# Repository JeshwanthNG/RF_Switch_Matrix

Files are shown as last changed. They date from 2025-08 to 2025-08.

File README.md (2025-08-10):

# RF_Switch_Matrix
Project Implementing RF Switch Matrix, Includes hardware, software and PC application 

## Getting Started

### Prerequisites

- **Windows** for GUI development
- **Visual Studio 2022** with .NET desktop development workload
- **STM32CubeIDE** or **STM32CubeMX** with preferred IDE
- **STM32F439ZI** development board

### Clone the repository

```bash
git clone https://github.com/JeshwanthNG/RF_Switch_Matrix.git
cd RF_Switch_Matrix

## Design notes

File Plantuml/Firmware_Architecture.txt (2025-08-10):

@startuml

skinparam shadowing false
skinparam defaultTextAlignment center
skinparam componentStyle rectangle
skinparam packageStyle rectangle
skinparam ArrowColor Black
skinparam Rectangle {
  BorderColor Black
}

' =================== LAYERS ===================
package "Application Layer" #F0F8FF {
  component "StartThread\n(init, netif, LwIP bring-up)" as APP_START
  component "DisplayTask\n(UI state machine)" as APP_DISP
  component "KeypadTask\n(4x4 scan + debounce)" as APP_KEYPAD
  component "UART Console Task\n(prvUARTCommandConsoleTask)" as APP_CLI
  component "RF Switch Control\n(rfswitch.c)" as APP_RFSW
  component "TCP Echo Server\n(tcpecho.c)" as APP_TCP
  component "UDP Echo Server\n(udpecho.c)" as APP_UDP
}

package "Middleware" #F5FFFA {
  component "FreeRTOS\n(CMSIS-RTOS API)" as OS
  component "FreeRTOS+CLI\n(FreeRTOS_CLI.c)" as CLI
  component "LwIP (Netconn)\n(app_ethernet.c, ethernetif.c)" as LWIP
  component "EEPROM Emulation\n(eeprom.c)" as EEP
}

package "HAL / Drivers" #FFFFF0 {
  component "STM32 HAL\n(GPIO, ETH, USART, TIM)" as HAL
  component "GPIO Driver\n(gpio.c)" as DRV_GPIO
  component "USART Driver\n(usart.c)" as DRV_USART
}

package "Hardware" #FFF0F5 {
  component "STM32F439ZI\n(Cortex-M4F)" as MCU
  component "ETH PHY + RJ45" as ETHPHY
  component "LCD (Text)\n(lcd.c)" as LCD
  component "Keypad 4x4\n(Keypad.c)" as KEYPAD
  component "RF Switch Matrix (8× 1P4T)\n(GPIO-controlled)" as RFMAT
  component "Flash (EEPROM Emu)" as FLASH
}

' =================== QUEUES / IPC ===================
queue "keypadQueue\n(xQueue<KEYPAD_CODES>)" as Q_KEYPAD

' =================== RELATIONSHIPS: APP -> MW -> DRV -> HW ===================

' App tasks use RTOS
APP_START -down-> OS
APP_DISP  -down-> OS
APP_KEYPAD -down-> OS
APP_CLI -down-> OS
APP_TCP -down-> OS
APP_UDP -down-> OS
APP_RFSW -down-> OS

' CLI uses FreeRTOS+CLI
APP_CLI -down-> CLI

' Networking
APP_START -down-> LWIP : netif init\nDHCP_thread
APP_TCP -down-> LWIP : Netconn API
APP_UDP -down-> LWIP : Netconn API

' EEPROM emulation
APP_DISP -down-> EEP : load/save config
APP_CLI  -down-> EEP : read/write params

' RF switch control module
APP_DISP -down-> APP_RFSW : set routes
APP_CLI  -down-> APP_RFSW : cli: switch-set\nstatus

' Display <-> Keypad via queue
APP_KEYPAD -right-> Q_KEYPAD : xQueueSend
Q_KEYPAD -right-> APP_DISP : xQueueReceive

' Middleware to HAL/Drivers
LWIP -down-> HAL
CLI  -down-> HAL
EEP  -down-> HAL

' Drivers to HAL core
DRV_GPIO -down-> HAL
DRV_USART -down-> HAL

' HAL to MCU / Peripherals
HAL -down-> MCU
HAL -down-> ETHPHY
HAL -down-> LCD
HAL -down-> KEYPAD

' Drivers to Hardware via HAL
APP_RFSW -down-> DRV_GPIO : GPIO writes
DRV_GPIO -down-> RFMAT : select lines

APP_CLI -down-> DRV_USART : UART RX/TX
DRV_USART -down-> MCU

' UI plumbing
APP_DISP -down-> LCD : print strings\nmenus
APP_KEYPAD -down-> KEYPAD : scan rows/cols

' LwIP plumbing
LWIP -down-> ETHPHY : MAC <-> PHY

' EEPROM emulation uses on-chip Flash
EEP -down-> FLASH : pages/sectors

' =================== NOTES ===================
note right of APP_START
- Initializes HAL, clocks
- Starts LwIP (netif, DHCP_thread)
- Spawns UI/CLI tasks
end note

note right of APP_DISP
- Startup screen, menu
- Switch status page
- Settings pages (ETH, baud)
end note

note right of APP_RFSW
- Maps INx <-> OUTy
- Uses GPIO pin tables
- Readback status APIs
end note

note bottom of APP_CLI
Commands in CLI-commands.c:
- switch set/get
- show status
- net info (IP/DHCP)
end note

@enduml

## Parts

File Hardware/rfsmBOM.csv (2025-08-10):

Id | Designator | Package | Quantity | Designation | Supplier and ref
1 | J14,J13 | PinSocket_1x02_P2.54mm_Vertical | 2 | Conn_01x02_Male
2 | U1 | ST_Morpho_Connector_144_STLink | 1 | NUCLEO144-F439ZI
3 | C15,C16,C14,C13,C12,C11,C10,C9,C1,C4,C5,C7 | C_0805_2012Metric_Pad1.18x1.45mm_HandSolder | 12 | 0.1uf
4 | C17,C2,C8 | CP_EIA-2012-12_Kemet-R_Pad1.30x1.05mm_HandSolder | 3 | 22uf
5 | REF**,REF**,REF**,REF** | MountingHole_2.2mm_M2 | 4 | MountingHole_2.2mm_M2
6 | U9,U3,U4,U5,U6,U7,U8,U10 | DIP-14_W7.62mm_Socket | 8 | 74125
7 | C3,C6 | CP_EIA-2012-12_Kemet-R_Pad1.30x1.05mm_HandSolder | 2 | 10uf
8 | J1 | BarrelJack_Horizontal | 1 | Barrel_Jack_Switch_Pin3Ring
9 | J2 | PinSocket_1x16_P2.54mm_Vertical | 1 | LCD20x4
10 | J3 | PinSocket_1x08_P2.54mm_Vertical | 1 | Conn_01x08_Male
11 | J4 | JST_EH_B4B-EH-A_1x04_P2.50mm_Vertical | 1 | Conn_01x04_Male
12 | J5,J6,J7,J8,J9,J10,J11,J12 | JST_EH_B6B-EH-A_1x06_P2.50mm_Vertical | 8 | Conn_01x06_Male
13 | Q1 | SOT-23 | 1 | BC547
14 | R1 | R_0805_2012Metric_Pad1.20x1.40mm_HandSolder | 1 | 1k
15 | R2,R3,R4,R5,R6 | R_0805_2012Metric_Pad1.20x1.40mm_HandSolder | 5 | 4.7k
16 | RV1 | Potentiometer_Bourns_3296W_Vertical | 1 | R_POT
17 | U2,U11 | TO-220-3_Vertical | 2 | L7805

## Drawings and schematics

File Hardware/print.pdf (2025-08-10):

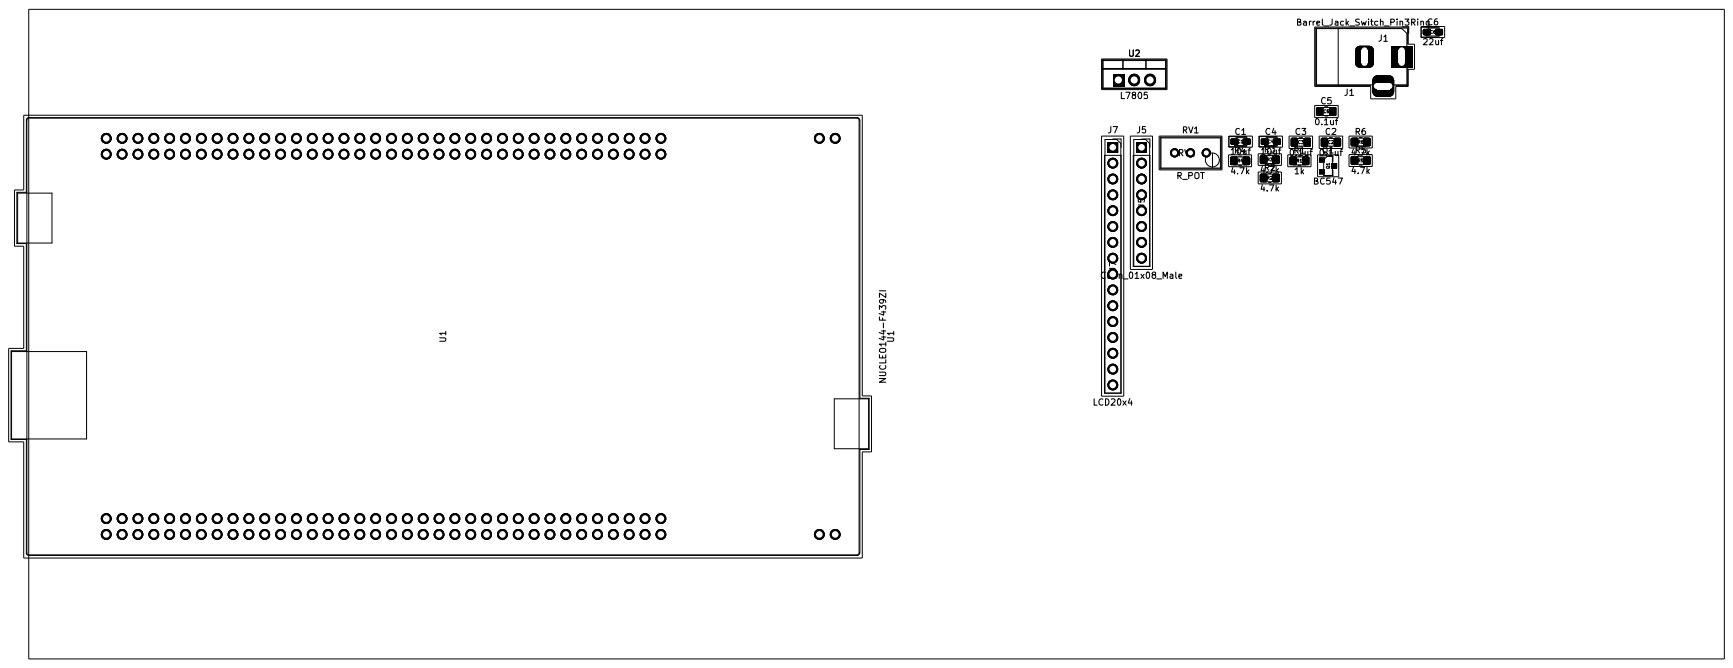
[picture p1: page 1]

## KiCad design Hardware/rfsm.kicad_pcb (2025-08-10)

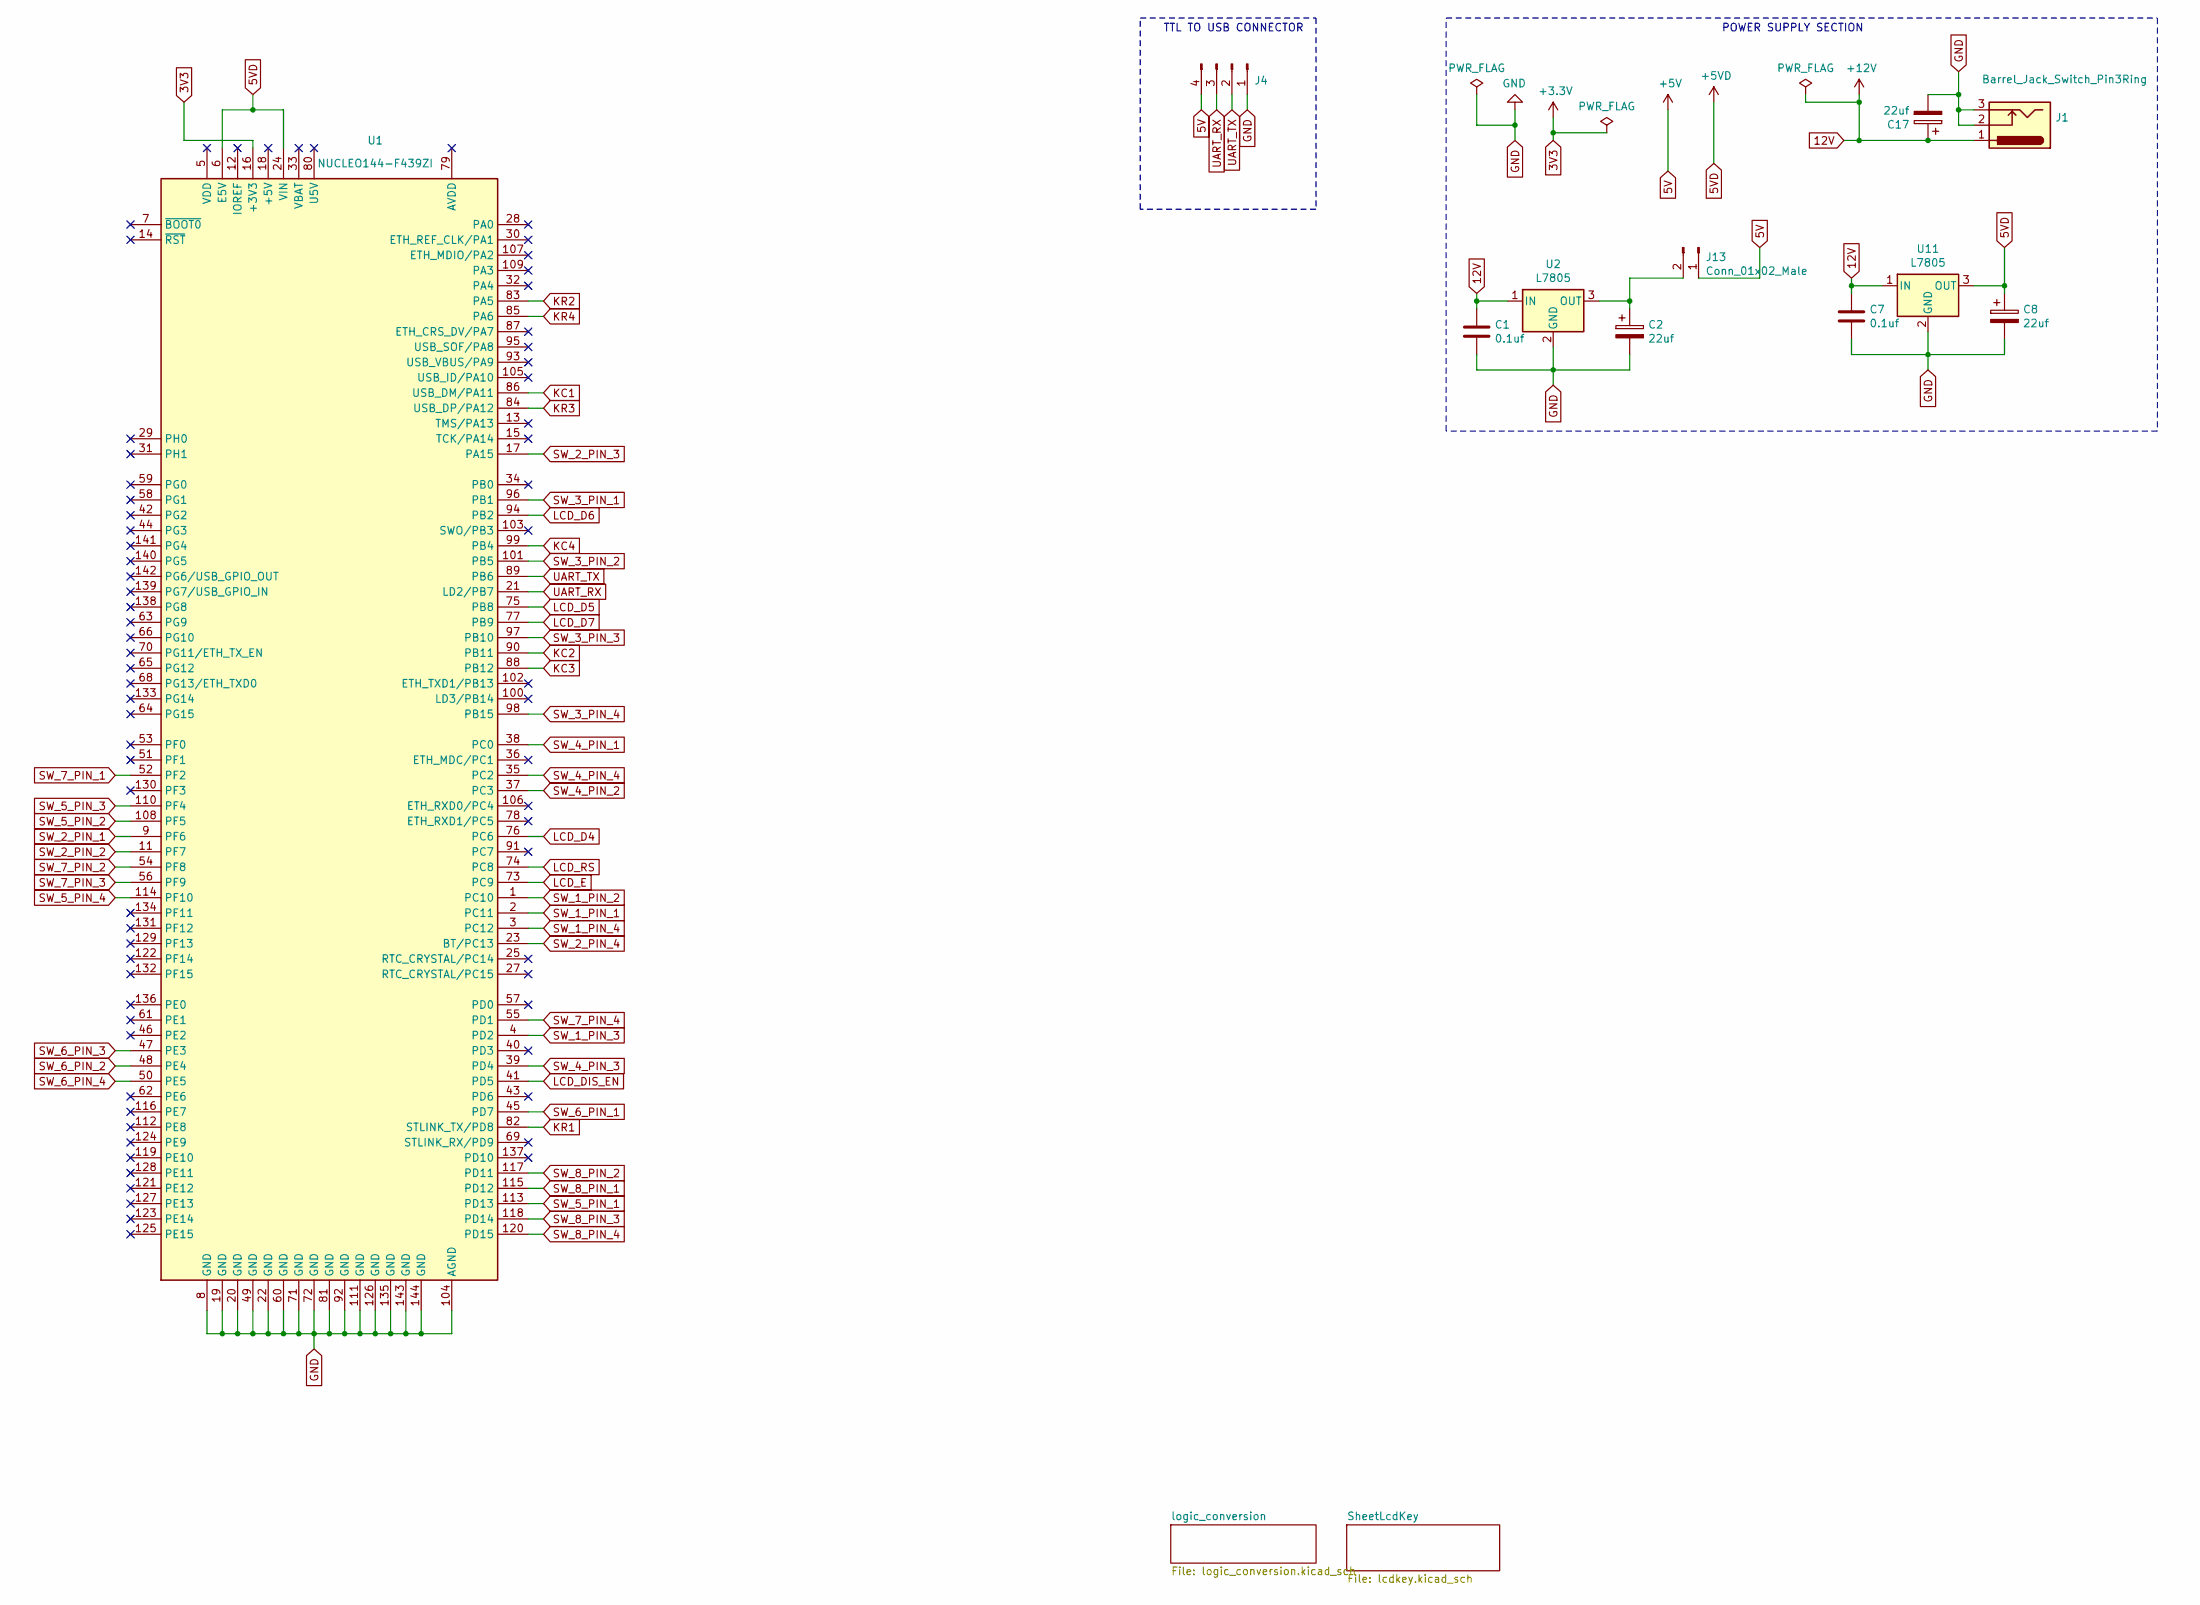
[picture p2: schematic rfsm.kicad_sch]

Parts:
C1, C7: 0.1uf; C_0805_2012Metric_Pad1.18x1.45mm_HandSolder
C2, C8, C17: 22uf; CP_EIA-2012-12_Kemet-R_Pad1.30x1.05mm_HandSolder
J1: Barrel_Jack_Switch_Pin3Ring; BarrelJack_Horizontal
J4: Conn_01x04_Male; JST_EH_B4B-EH-A_1x04_P2.50mm_Vertical
J13: Conn_01x02_Male; PinSocket_1x02_P2.54mm_Vertical
U1: NUCLEO144-F439ZI; ST_Morpho_Connector_144_STLink
U2, U11: L7805; TO-220-3_Vertical

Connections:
3V3: U1.16 (+3V3); also elsewhere on the board
5V: J4.4, J13.1; also elsewhere on the board
5VD: C8.1, U1.6 (E5V), U1.24 (VIN), U11.3 (OUT)
12V: C1.1, C7.1, C17.1, J1.1, U2.1 (IN), U11.1 (IN); also elsewhere on the board
GND: C1.2, C2.2, C7.2, C8.2, C17.2, J1.2, J1.3, J4.1, U1.8 (GND), U1.19 (GND), U1.20 (GND), U1.22 (GND), U1.49 (GND), U1.60 (GND), U1.71 (GND), U1.72 (GND), U1.81 (GND), U1.92 (GND), U1.104 (AGND), U1.111 (GND), U1.126 (GND), U1.135 (GND), U1.143 (GND), U1.144 (GND), U2.2 (GND), U11.2 (GND); also elsewhere on the board
KC1: U1.86 (USB_DM/PA11); also elsewhere on the board
KC2: U1.90 (PB11); also elsewhere on the board
KC3: U1.88 (PB12); also elsewhere on the board
KC4: U1.99 (PB4); also elsewhere on the board
KR1: U1.82 (STLINK_TX/PD8); also elsewhere on the board
KR2: U1.83 (PA5); also elsewhere on the board
KR3: U1.84 (USB_DP/PA12); also elsewhere on the board
KR4: U1.85 (PA6); also elsewhere on the board
LCD_D4: U1.76 (PC6); also elsewhere on the board
LCD_D5: U1.75 (PB8); also elsewhere on the board
LCD_D6: U1.94 (PB2); also elsewhere on the board
LCD_D7: U1.77 (PB9); also elsewhere on the board
LCD_DIS_EN: U1.41 (PD5); also elsewhere on the board
LCD_E: U1.73 (PC9); also elsewhere on the board
LCD_RS: U1.74 (PC8); also elsewhere on the board
unnamed: C2.1, J13.2, U2.3 (OUT)
SW_1_PIN_1: U1.2 (PC11); also elsewhere on the board
SW_1_PIN_2: U1.1 (PC10); also elsewhere on the board
SW_1_PIN_3: U1.4 (PD2); also elsewhere on the board
SW_1_PIN_4: U1.3 (PC12); also elsewhere on the board
SW_2_PIN_1: U1.9 (PF6); also elsewhere on the board
SW_2_PIN_2: U1.11 (PF7); also elsewhere on the board
SW_2_PIN_3: U1.17 (PA15); also elsewhere on the board
SW_2_PIN_4: U1.23 (BT/PC13); also elsewhere on the board
SW_3_PIN_1: U1.96 (PB1); also elsewhere on the board
SW_3_PIN_2: U1.101 (PB5); also elsewhere on the board
SW_3_PIN_3: U1.97 (PB10); also elsewhere on the board
SW_3_PIN_4: U1.98 (PB15); also elsewhere on the board
SW_4_PIN_1: U1.38 (PC0); also elsewhere on the board
SW_4_PIN_2: U1.37 (PC3); also elsewhere on the board
SW_4_PIN_3: U1.39 (PD4); also elsewhere on the board
SW_4_PIN_4: U1.35 (PC2); also elsewhere on the board
SW_5_PIN_1: U1.113 (PD13); also elsewhere on the board
SW_5_PIN_2: U1.108 (PF5); also elsewhere on the board
SW_5_PIN_3: U1.110 (PF4); also elsewhere on the board
SW_5_PIN_4: U1.114 (PF10); also elsewhere on the board
SW_6_PIN_1: U1.45 (PD7); also elsewhere on the board
SW_6_PIN_2: U1.48 (PE4); also elsewhere on the board
SW_6_PIN_3: U1.47 (PE3); also elsewhere on the board
SW_6_PIN_4: U1.50 (PE5); also elsewhere on the board
SW_7_PIN_1: U1.52 (PF2); also elsewhere on the board
SW_7_PIN_2: U1.54 (PF8); also elsewhere on the board
SW_7_PIN_3: U1.56 (PF9); also elsewhere on the board
SW_7_PIN_4: U1.55 (PD1); also elsewhere on the board
SW_8_PIN_1: U1.115 (PD12); also elsewhere on the board
SW_8_PIN_2: U1.117 (PD11); also elsewhere on the board
SW_8_PIN_3: U1.118 (PD14); also elsewhere on the board
SW_8_PIN_4: U1.120 (PD15); also elsewhere on the board
UART_RX: J4.3, U1.21 (LD2/PB7)
UART_TX: J4.2, U1.89 (PB6)

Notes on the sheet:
POWER SUPPLY SECTION
TTL TO USB CONNECTOR

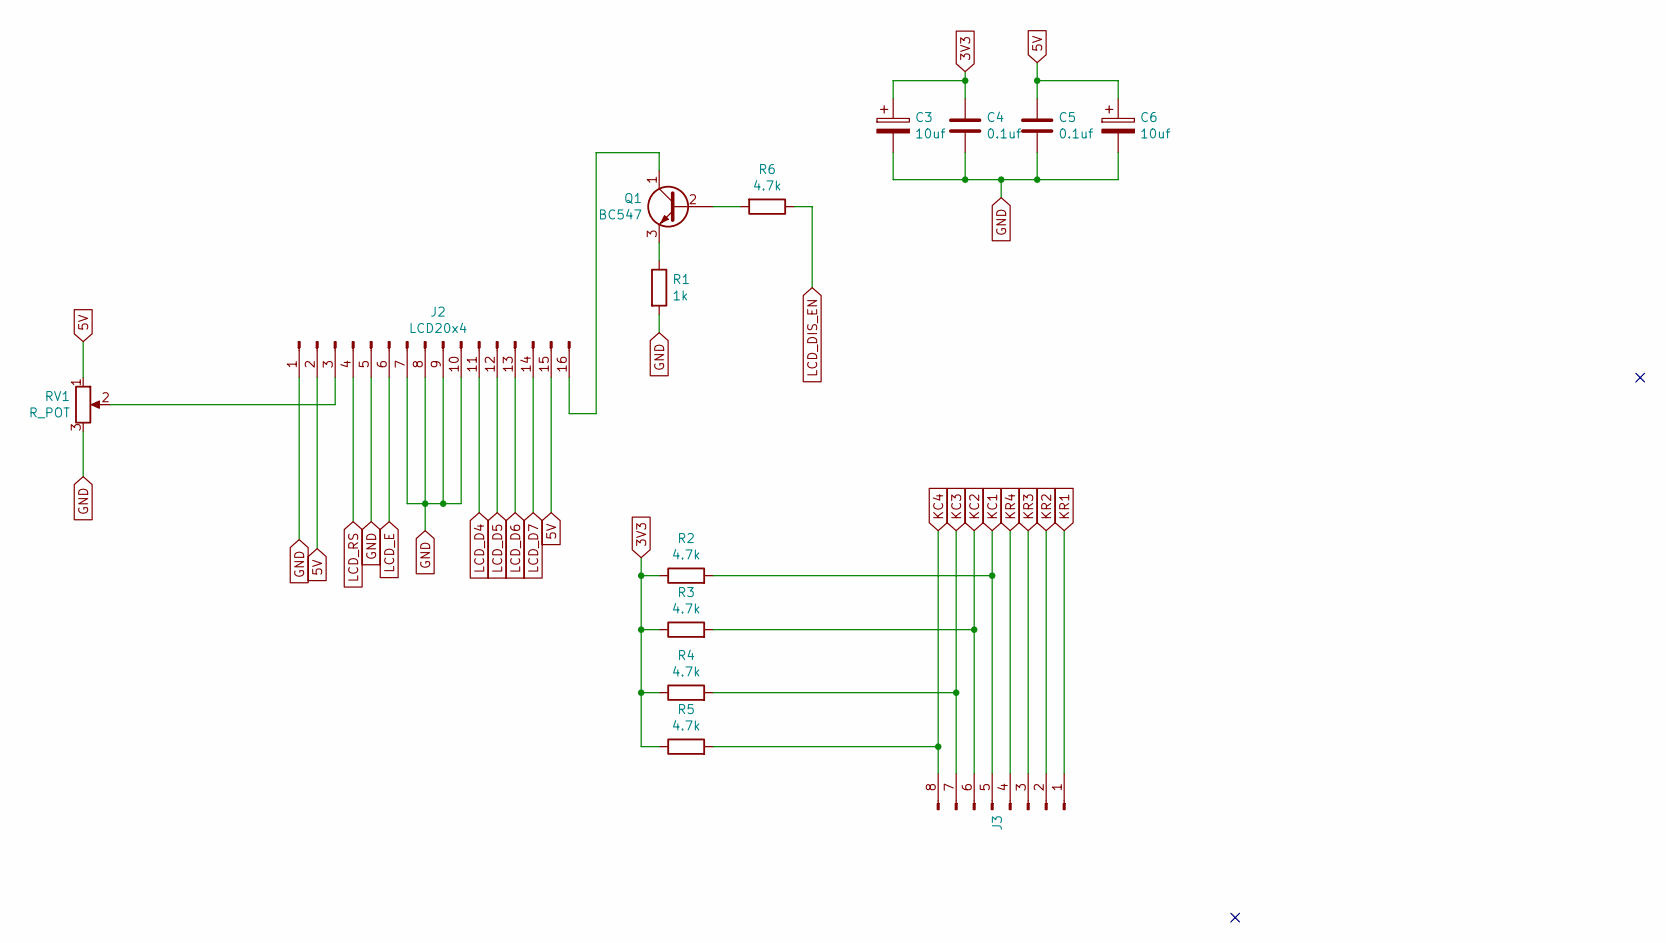
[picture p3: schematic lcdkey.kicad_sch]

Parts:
C3, C6: 10uf; CP_EIA-2012-12_Kemet-R_Pad1.30x1.05mm_HandSolder
C4, C5: 0.1uf; C_0805_2012Metric_Pad1.18x1.45mm_HandSolder
J2: LCD20x4; PinSocket_1x16_P2.54mm_Vertical
J3: Conn_01x08_Male; PinSocket_1x08_P2.54mm_Vertical
Q1: BC547; SOT-23
R1: 1k; R_0805_2012Metric_Pad1.20x1.40mm_HandSolder
R2, R3, R4, R5, R6: 4.7k; R_0805_2012Metric_Pad1.20x1.40mm_HandSolder
RV1: R_POT; Potentiometer_Bourns_3296W_Vertical

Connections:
3V3: C3.1, C4.1, R2.1, R3.1, R4.1, R5.1; also elsewhere on the board
5V: C5.1, C6.1, J2.2, J2.15, RV1.1; also elsewhere on the board
GND: C3.2, C4.2, C5.2, C6.2, J2.1, J2.5, J2.7, J2.8, J2.9, J2.10, R1.2, RV1.3; also elsewhere on the board
KC1: J3.5, R2.2; also elsewhere on the board
KC2: J3.6, R3.2; also elsewhere on the board
KC3: J3.7, R4.2; also elsewhere on the board
KC4: J3.8, R5.2; also elsewhere on the board
KR1: J3.1; also elsewhere on the board
KR2: J3.2; also elsewhere on the board
KR3: J3.3; also elsewhere on the board
KR4: J3.4; also elsewhere on the board
LCD_D4: J2.11; also elsewhere on the board
LCD_D5: J2.12; also elsewhere on the board
LCD_D6: J2.13; also elsewhere on the board
LCD_D7: J2.14; also elsewhere on the board
LCD_DIS_EN: R6.1; also elsewhere on the board
LCD_E: J2.6; also elsewhere on the board
LCD_RS: J2.4; also elsewhere on the board
unnamed: J2.3, RV1.2
unnamed: J2.16, Q1.1 (C)
unnamed: Q1.2 (B), R6.2
unnamed: Q1.3 (E), R1.1

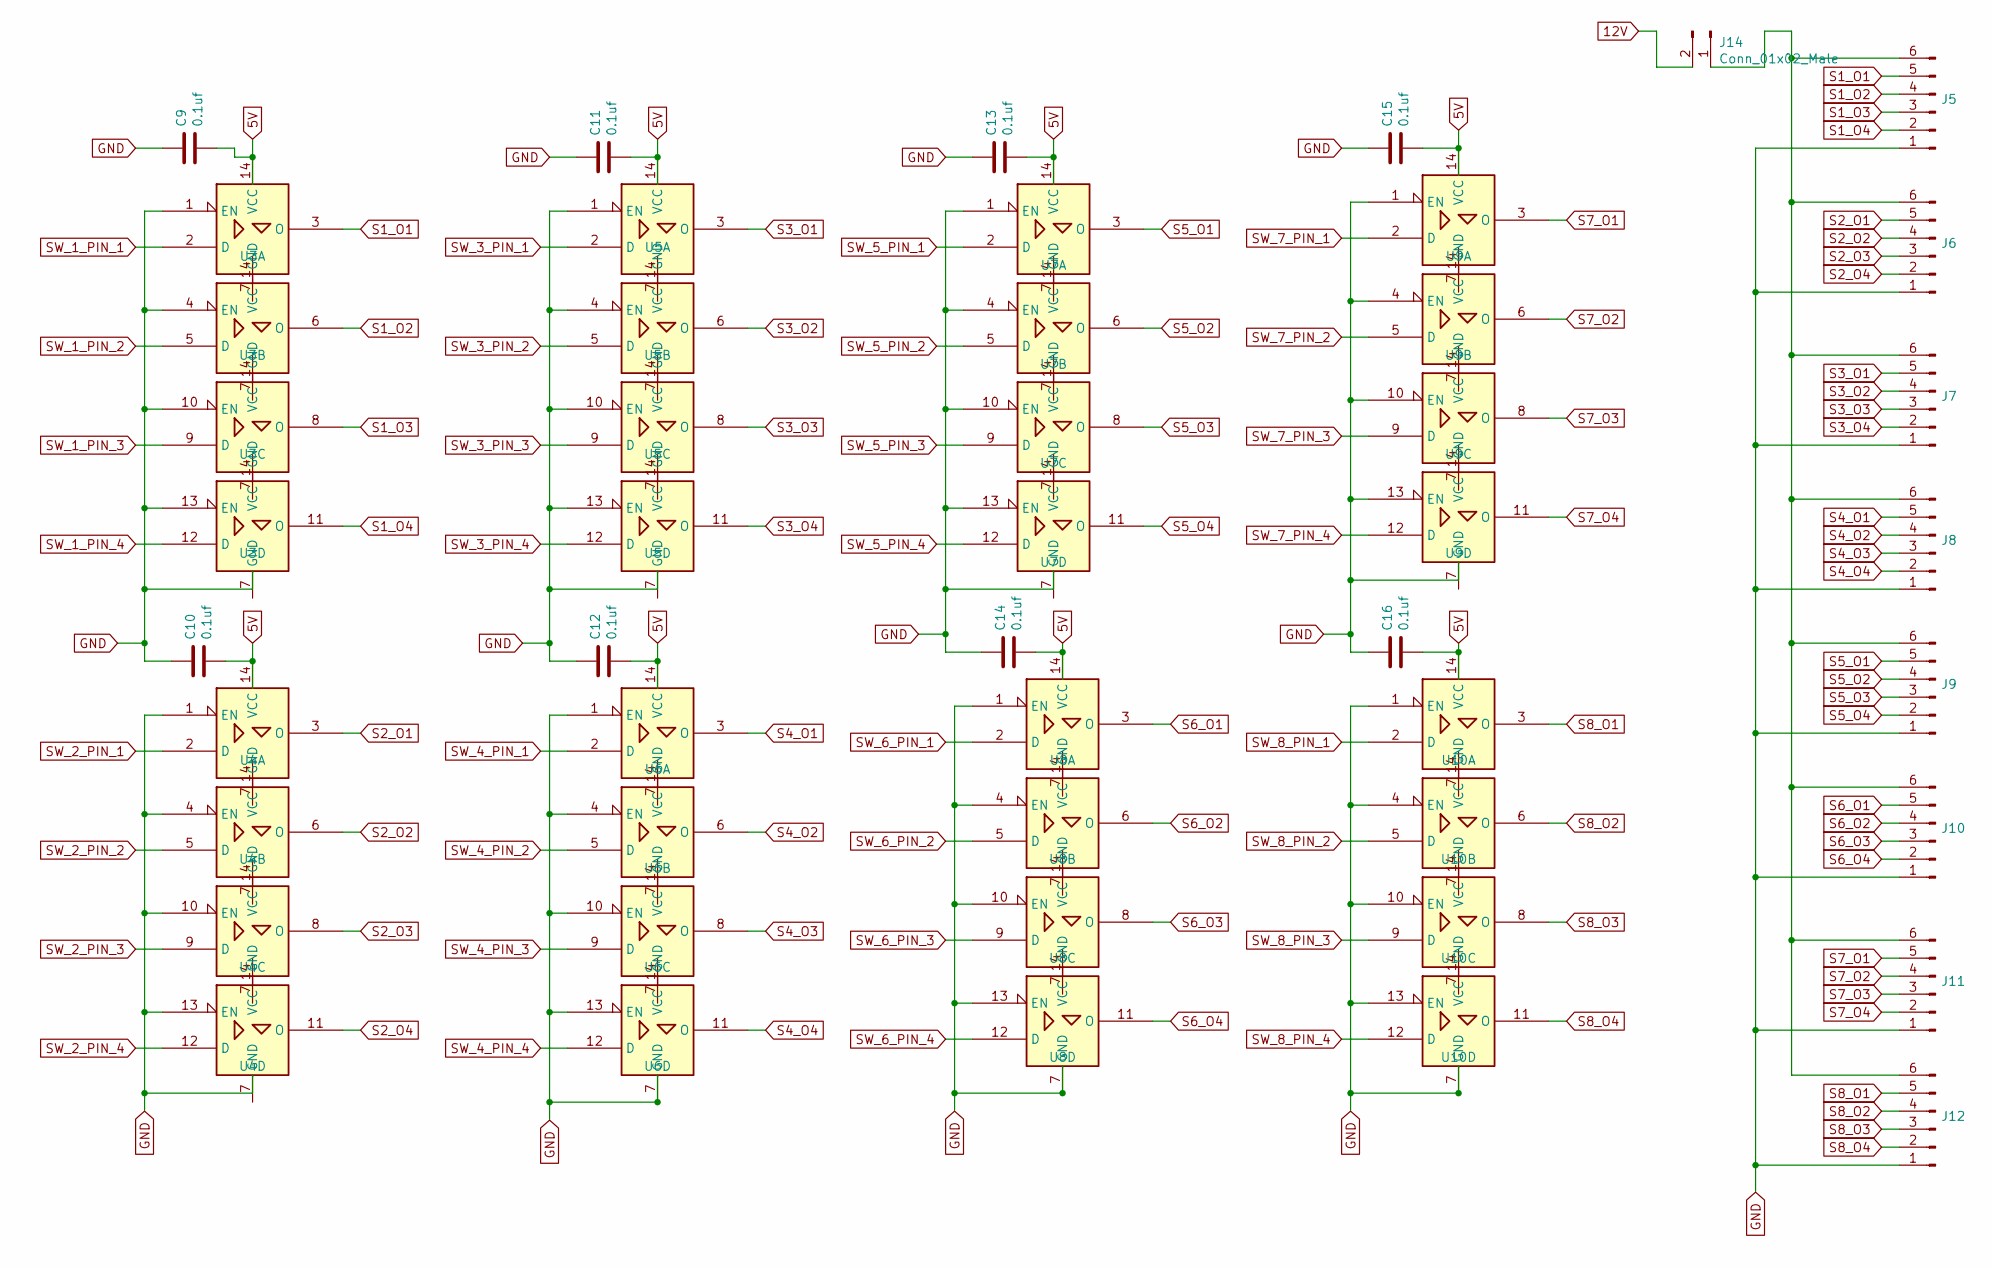
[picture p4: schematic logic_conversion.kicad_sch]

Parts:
C9, C10, C11, C12, C13, C14, C15, C16: 0.1uf; C_0805_2012Metric_Pad1.18x1.45mm_HandSolder
J5, J6, J7, J8, J9, J10, J11, J12: Conn_01x06_Male; JST_EH_B6B-EH-A_1x06_P2.50mm_Vertical
J14: Conn_01x02_Male; PinSocket_1x02_P2.54mm_Vertical
U3, U4, U5, U6, U7, U8, U9, U10: 74125; DIP-14_W7.62mm_Socket

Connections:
5V: C9.2, C10.2, C11.2, C12.2, C13.2, C14.2, C15.2, C16.2, U3.14 (VCC), U4.14 (VCC), U5.14 (VCC), U6.14 (VCC), U7.14 (VCC), U8.14 (VCC), U9.14 (VCC), U10.14 (VCC); also elsewhere on the board
12V: J14.2; also elsewhere on the board
GND: C9.1, C10.1, C11.1, C12.1, C13.1, C14.1, C15.1, C16.1, J5.1, J6.1, J7.1, J8.1, J9.1, J10.1, J11.1, J12.1, U3.1 (EN), U3.4 (EN), U3.7 (GND), U3.10 (EN), U3.13 (EN), U4.1 (EN), U4.4 (EN), U4.7 (GND), U4.10 (EN), U4.13 (EN), U5.1 (EN), U5.4 (EN), U5.7 (GND), U5.10 (EN), U5.13 (EN), U6.1 (EN), U6.4 (EN), U6.7 (GND), U6.10 (EN), U6.13 (EN), U7.1 (EN), U7.4 (EN), U7.7 (GND), U7.10 (EN), U7.13 (EN), U8.1 (EN), U8.4 (EN), U8.7 (GND), U8.10 (EN), U8.13 (EN), U9.1 (EN), U9.4 (EN), U9.7 (GND), U9.10 (EN), U9.13 (EN), U10.1 (EN), U10.4 (EN), U10.7 (GND), U10.10 (EN), U10.13 (EN); also elsewhere on the board
unnamed: J5.6, J6.6, J7.6, J8.6, J9.6, J10.6, J11.6, J12.6, J14.1
S1_O1: J5.5, U3.3 (O)
S1_O2: J5.4, U3.6 (O)
S1_O3: J5.3, U3.8 (O)
S1_O4: J5.2, U3.11 (O)
S2_O1: J6.5, U4.3 (O)
S2_O2: J6.4, U4.6 (O)
S2_O3: J6.3, U4.8 (O)
S2_O4: J6.2, U4.11 (O)
S3_O1: J7.5, U5.3 (O)
S3_O2: J7.4, U5.6 (O)
S3_O3: J7.3, U5.8 (O)
S3_O4: J7.2, U5.11 (O)
S4_O1: J8.5, U6.3 (O)
S4_O2: J8.4, U6.6 (O)
S4_O3: J8.3, U6.8 (O)
S4_O4: J8.2, U6.11 (O)
S5_O1: J9.5, U7.3 (O)
S5_O2: J9.4, U7.6 (O)
S5_O3: J9.3, U7.8 (O)
S5_O4: J9.2, U7.11 (O)
S6_O1: J10.5, U8.3 (O)
S6_O2: J10.4, U8.6 (O)
S6_O3: J10.3, U8.8 (O)
S6_O4: J10.2, U8.11 (O)
S7_O1: J11.5, U9.3 (O)
S7_O2: J11.4, U9.6 (O)
S7_O3: J11.3, U9.8 (O)
S7_O4: J11.2, U9.11 (O)
S8_O1: J12.5, U10.3 (O)
S8_O2: J12.4, U10.6 (O)
S8_O3: J12.3, U10.8 (O)
S8_O4: J12.2, U10.11 (O)
SW_1_PIN_1: U3.2 (D); also elsewhere on the board
SW_1_PIN_2: U3.5 (D); also elsewhere on the board
SW_1_PIN_3: U3.9 (D); also elsewhere on the board
SW_1_PIN_4: U3.12 (D); also elsewhere on the board
SW_2_PIN_1: U4.2 (D); also elsewhere on the board
SW_2_PIN_2: U4.5 (D); also elsewhere on the board
SW_2_PIN_3: U4.9 (D); also elsewhere on the board
SW_2_PIN_4: U4.12 (D); also elsewhere on the board
SW_3_PIN_1: U5.2 (D); also elsewhere on the board
SW_3_PIN_2: U5.5 (D); also elsewhere on the board
SW_3_PIN_3: U5.9 (D); also elsewhere on the board
SW_3_PIN_4: U5.12 (D); also elsewhere on the board
SW_4_PIN_1: U6.2 (D); also elsewhere on the board
SW_4_PIN_2: U6.5 (D); also elsewhere on the board
SW_4_PIN_3: U6.9 (D); also elsewhere on the board
SW_4_PIN_4: U6.12 (D); also elsewhere on the board
SW_5_PIN_1: U7.2 (D); also elsewhere on the board
SW_5_PIN_2: U7.5 (D); also elsewhere on the board
SW_5_PIN_3: U7.9 (D); also elsewhere on the board
SW_5_PIN_4: U7.12 (D); also elsewhere on the board
SW_6_PIN_1: U8.2 (D); also elsewhere on the board
SW_6_PIN_2: U8.5 (D); also elsewhere on the board
SW_6_PIN_3: U8.9 (D); also elsewhere on the board
SW_6_PIN_4: U8.12 (D); also elsewhere on the board
SW_7_PIN_1: U9.2 (D); also elsewhere on the board
SW_7_PIN_2: U9.5 (D); also elsewhere on the board
SW_7_PIN_3: U9.9 (D); also elsewhere on the board
SW_7_PIN_4: U9.12 (D); also elsewhere on the board
SW_8_PIN_1: U10.2 (D); also elsewhere on the board
SW_8_PIN_2: U10.5 (D); also elsewhere on the board
SW_8_PIN_3: U10.9 (D); also elsewhere on the board
SW_8_PIN_4: U10.12 (D); also elsewhere on the board

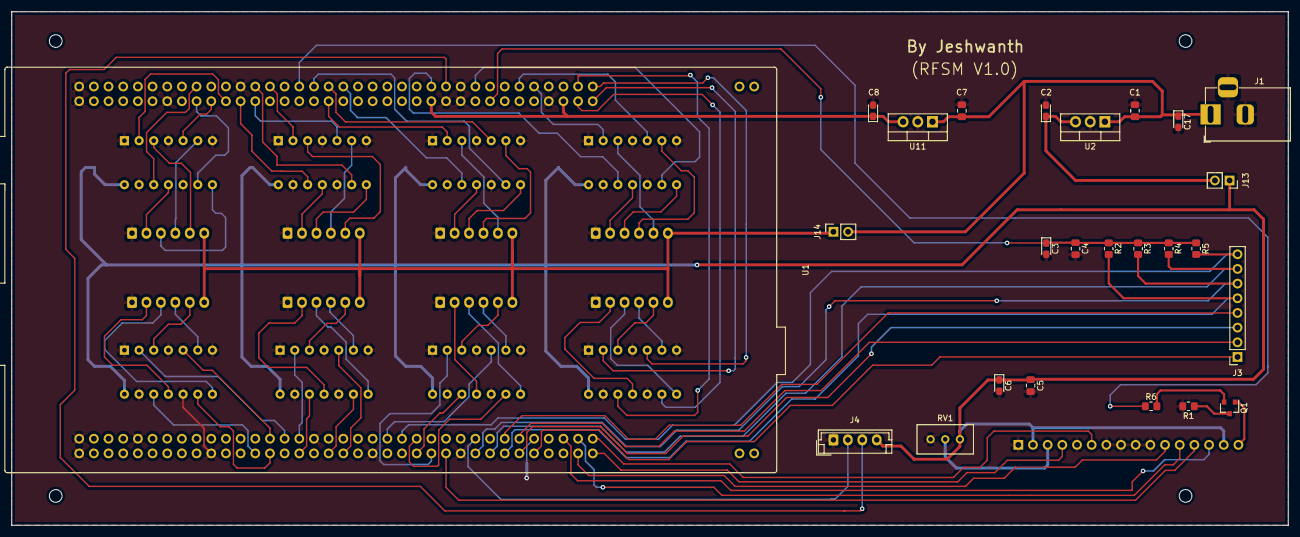
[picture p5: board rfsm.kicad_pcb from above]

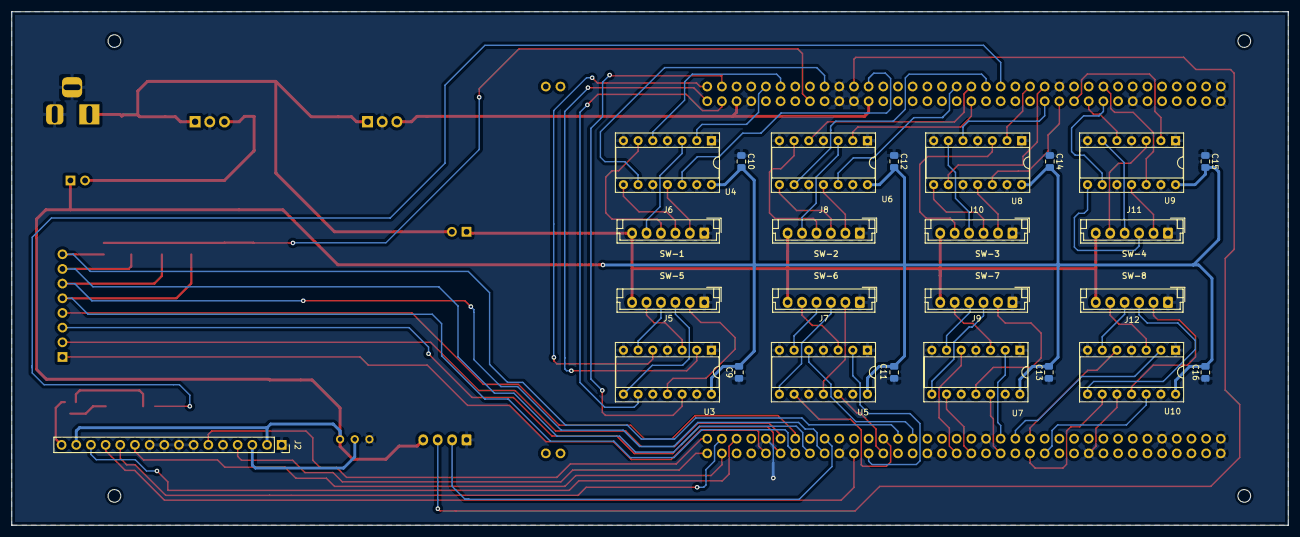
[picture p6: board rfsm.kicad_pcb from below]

Board: 2 copper layers, 221.0 x 88.9 mm, 50 parts (25 on the bottom side), 92 nets.

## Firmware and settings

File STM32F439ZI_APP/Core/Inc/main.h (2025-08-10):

/**
  ******************************************************************************
  * @file    LwIP/LwIP_HTTP_Server_Netconn_RTOS/Inc/main.h 
  * @author  MCD Application Team
  * @brief   Header for main.c module
  ******************************************************************************
  * @attention
  *
  * <h2><center>&copy; Copyright � 2017 STMicroelectronics International N.V. 
  * All rights reserved.</center></h2>
  *
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
  ******************************************************************************
  */
/* Define to prevent recursive inclusion -------------------------------------*/
#ifndef __MAIN_H
#define __MAIN_H

#ifdef __cplusplus
 extern "C" {
#endif

/* Includes ------------------------------------------------------------------*/
#include "stm32f4xx_hal.h"

   
#include "../Middlewares/Third_Party/FreeRTOS/Source/CMSIS_RTOS/cmsis_os.h"
#include <stdio.h>

/* Exported types ------------------------------------------------------------*/
/* Exported constants --------------------------------------------------------*/ 
#define USE_DHCP       /* enable DHCP, if disabled static address is used*/
 
/*Static IP ADDRESS*/
#define IP_ADDR0   (uint8_t) 192
#define IP_ADDR1   (uint8_t) 168
#define IP_ADDR2   (uint8_t) 0
#define IP_ADDR3   (uint8_t) 10
   
/*NETMASK*/
#define NETMASK_ADDR0   (uint8_t) 255
#define NETMASK_ADDR1   (uint8_t) 255
#define NETMASK_ADDR2   (uint8_t) 255
#define NETMASK_ADDR3   (uint8_t) 0

/*Gateway Address*/
#define GW_ADDR0   (uint8_t) 192
#define GW_ADDR1   (uint8_t) 168
#define GW_ADDR2   (uint8_t) 0
#define GW_ADDR3   (uint8_t) 1 

#define true       (1u)
#define false      (0u)

/* Exported macro ------------------------------------------------------------*/
/* Exported functions ------------------------------------------------------- */  

void Error_Handler(void);


#ifdef __cplusplus
}
#endif

#endif /* __MAIN_H */


/************************ (C) COPYRIGHT STMicroelectronics *****END OF FILE****/

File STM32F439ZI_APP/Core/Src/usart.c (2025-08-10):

/**
  ******************************************************************************
  * File Name          : USART.c
  * Description        : This file provides code for the configuration
  *                      of the USART instances.
  ******************************************************************************
  * @attention
  *
  * <h2><center>&copy; Copyright (c) 2020 STMicroelectronics.
  * All rights reserved.</center></h2>
  *
  * This software component is licensed by ST under BSD 3-Clause license,
  * the "License"; You may not use this file except in compliance with the
  * License. You may obtain a copy of the License at:
  *                        opensource.org/licenses/BSD-3-Clause
  *
  ******************************************************************************
  */

/* Includes ------------------------------------------------------------------*/
#include "usart.h"

#define USE_RS485


UART_HandleTypeDef huart1;

#ifdef USE_RS485
UART_HandleTypeDef huart2;
#endif

/* USART1 init function */

void MX_USART1_UART_Init(void)
{

  huart1.Instance = USART1;
  huart1.Init.BaudRate = 19200;//115200;
  huart1.Init.WordLength = UART_WORDLENGTH_8B;
  huart1.Init.StopBits = UART_STOPBITS_1;
  huart1.Init.Parity = UART_PARITY_NONE;
  huart1.Init.Mode = UART_MODE_TX_RX;
  huart1.Init.HwFlowCtl = UART_HWCONTROL_NONE;
  huart1.Init.OverSampling = UART_OVERSAMPLING_16;


  if (HAL_UART_Init(&huart1) != HAL_OK)
  {
    Error_Handler();
  }
}

#ifdef USE_RS485
void MX_USART2_UART_Init(void)
{

  huart2.Instance = USART2;
  huart2.Init.BaudRate = 19200;//115200;
  huart2.Init.WordLength = UART_WORDLENGTH_8B;
  huart2.Init.StopBits = UART_STOPBITS_1;
  huart2.Init.Parity = UART_PARITY_NONE;
  huart2.Init.Mode = UART_MODE_TX_RX;
  huart2.Init.HwFlowCtl = UART_HWCONTROL_NONE;
  huart2.Init.OverSampling = UART_OVERSAMPLING_16;

  if (HAL_UART_Init(&huart2) != HAL_OK)
  {
    Error_Handler();
  }
}
#endif

void HAL_UART_MspInit(UART_HandleTypeDef* uartHandle)
{

  GPIO_InitTypeDef GPIO_InitStruct = {0};
  if(uartHandle->Instance==USART1)
  {
    /* USART1 clock enable */
    __HAL_RCC_USART1_CLK_ENABLE();

    __HAL_RCC_GPIOB_CLK_ENABLE();
    /**USART1 GPIO Configuration
    PB6     ------> USART1_TX
    PB7     ------> USART1_RX
    */
    GPIO_InitStruct.Pin = GPIO_PIN_6|GPIO_PIN_7;
    GPIO_InitStruct.Mode = GPIO_MODE_AF_PP;
    GPIO_InitStruct.Pull = GPIO_NOPULL;
    GPIO_InitStruct.Speed = GPIO_SPEED_FREQ_VERY_HIGH;
    GPIO_InitStruct.Alternate = GPIO_AF7_USART1;
    HAL_GPIO_Init(GPIOB, &GPIO_InitStruct);

    /* USART1 interrupt Init */
    HAL_NVIC_SetPriority(USART1_IRQn, 0, 0);
    HAL_NVIC_EnableIRQ(USART1_IRQn);
  }
#ifdef USE_RS485
  else if(uartHandle->Instance==USART2)
  {
    /* USART1 clock enable */
    __HAL_RCC_USART2_CLK_ENABLE();

    __HAL_RCC_GPIOD_CLK_ENABLE();
    /**USART1 GPIO Configuration
    PD5     ------> USART1_TX
    PD6     ------> USART1_RX
    PD4     ------> RTS
    */
    GPIO_InitStruct.Pin = GPIO_PIN_5|GPIO_PIN_6;
    GPIO_InitStruct.Mode = GPIO_MODE_AF_PP;
    GPIO_InitStruct.Pull = GPIO_NOPULL;
    GPIO_InitStruct.Speed = GPIO_SPEED_FREQ_VERY_HIGH;
    GPIO_InitStruct.Alternate = GPIO_AF7_USART1;
    HAL_GPIO_Init(GPIOB, &GPIO_InitStruct);

    GPIO_InitStruct.Pin = GPIO_PIN_4;
    GPIO_InitStruct.Mode = GPIO_MODE_OUTPUT_PP;
    GPIO_InitStruct.Pull = GPIO_PULLUP;
    GPIO_InitStruct.Speed = GPIO_SPEED_FREQ_LOW;
    HAL_GPIO_Init(GPIOD, &GPIO_InitStruct);

    /* USART1 interrupt Init */
    HAL_NVIC_SetPriority(USART2_IRQn, 0, 0);
    HAL_NVIC_EnableIRQ(USART2_IRQn);
  }
#endif
  else
  {

  }
}

void HAL_UART_MspDeInit(UART_HandleTypeDef* uartHandle)
{
  if(uartHandle->Instance==USART1)
  {
    /* Peripheral clock disable */
    __HAL_RCC_USART1_CLK_DISABLE();

    /**USART1 GPIO Configuration
    PB6     ------> USART1_TX
    PB7     ------> USART1_RX
    */
    HAL_GPIO_DeInit(GPIOB, GPIO_PIN_6|GPIO_PIN_7);

    /* USART1 interrupt Deinit */
    HAL_NVIC_DisableIRQ(USART1_IRQn);
  }
#ifdef USE_RS485
  else  if(uartHandle->Instance==USART2)
  {
    /* Peripheral clock disable */
    __HAL_RCC_USART2_CLK_DISABLE();

    /**USART1 GPIO Configuration
    PD5     ------> USART1_TX
    PD6     ------> USART1_RX
    PD4     ------> RTS
    */
    HAL_GPIO_DeInit(GPIOD, GPIO_PIN_4|GPIO_PIN_5|GPIO_PIN_6);

    /* USART1 interrupt Deinit */
    HAL_NVIC_DisableIRQ(USART2_IRQn);
  }
#endif
  else
  {
  }
}

/************************ (C) COPYRIGHT STMicroelectronics *****END OF FILE****/
